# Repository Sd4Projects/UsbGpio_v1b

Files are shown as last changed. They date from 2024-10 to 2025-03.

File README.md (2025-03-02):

# UsbGpio_v1b

Add gpio pins for (Mac, MiniPC, etc) via USB that do not have gpio pins to use.
If you only need a few gpio pins you may want to check out the Adafruit MCP2221 Breakout board Product ID: 4471.

UsbGpio board licensed under CERN OHL v.1.2 (Open Hardware Licence)

See CERN OHL v.1.2 for applicable conditions

http://ohwr.org/cernohl

USB Gpio Expansion board

Testing board design:

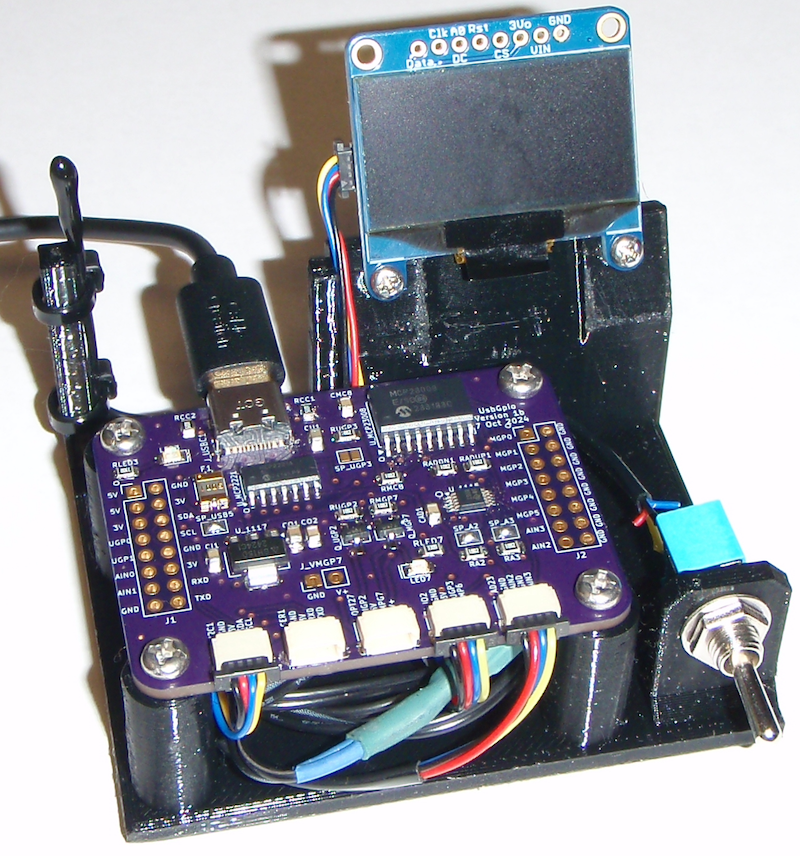
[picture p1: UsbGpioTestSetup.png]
finishedboard


Top view of board:

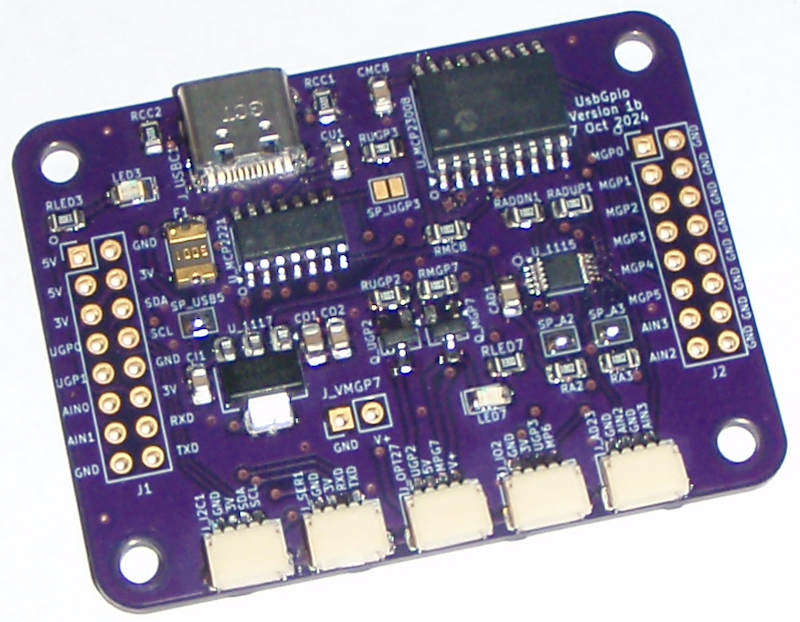
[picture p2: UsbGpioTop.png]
TopView


Bottom view of board:

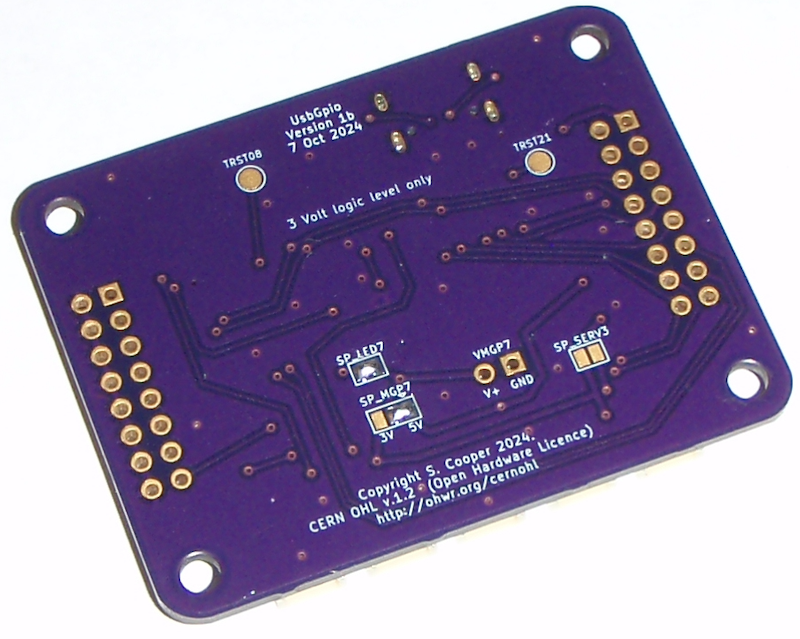
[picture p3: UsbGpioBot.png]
BottomView


Schematic PDF file: UsbGpio_v1b.SCH.pdf

Board PDF file: UsbGpio_v1b.PCB.pdf

BOM PDF file: UsbGpio_v1b.BOM.pdf

Designed with KiCad Version 8.0.4

UsbGpio source files included.

UsbGpio board features:
1. Four 16bit AtoD lines using an ADS1115 chip via I2C interface
2. MCP23008 chip via I2C interface
3. Two GPIO pins driving 2N7002 Mosfets for output.
4. I2C lines to a JST_SH Connector
5. UART (Serial) lines to a JST_SH Connector
6. USB C connector, USB 2.0

All data lines use 4-pin Qwiic/JST_SH connectores.

Bare board can be ordered from: https://oshpark.com/shared_projects/wGhxM2sL

Python 3 test program run on a Mac from Terminal window: macTestMcp2221.py (There are python libraries for other types of systems.)

Parts used for testing:
1. 10K Precision Epoxy Thermistor - 3950 NTC From adafruit Product ID: 372
2. Monochrome 1.3" 128x64 OLED graphic display - STEMMA QT / Qwiic From adafruit Product ID: 938
3. Mini Panel Mount SPDT Toggle Switch From adafruit Product ID: 3221
4. STEMMA QT / Qwiic JST SH 4-Pin Cable - 50mm Long From adafruit Product ID: 4399

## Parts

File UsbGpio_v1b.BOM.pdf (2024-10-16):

### UsbGpio

Reference | Qty | Value | Digi-Key_PN | Manufacturer Part# | Footprint
CAD1,CMC8,CO2 | 3 | 0.1uF | 399-C0805C104K3RAC7800CT-ND | C0805C104K3RAC7800 | Capacitor_SMD:C_0805_2012Metric_Pad1.18x1.45mm_HandSolder
CI1,CU1 | 2 | 1uF | 1276-1029-1-ND | CL21B105KBFNNNE | Capacitor_SMD:C_0805_2012Metric_Pad1.18x1.45mm_HandSolder
CO1 | 1 | 4.7uF | 399-5505-1-ND | C0805C475K3PACTU | Capacitor_SMD:C_0805_2012Metric_Pad1.18x1.45mm_HandSolder
F1 | 1 | 500ma | MF-PSMF050X-2CT-ND | MF-MSMF050-2 | Fuse:Fuse_1812_4532Metric
J1,J2 | 2 | Conn_02x08_Odd_Even | | | Connector_PinHeader_2.54mm:PinHeader_2x08_P2.54mm_Vertical
J_AD23,J_I2C1,J_IO2,J_OPT27,J_SER1 | 5 | Conn_01x04_MountingPin | 455-SM04B-SRSS-TBCT-ND | SM04B-SRSS-TB | Connector_JST:JST_SH_SM04B-SRSS-TB_1x04-1MP_P1.00mm_Horizontal
J_USBC1 | 1 | USB_C_Receptacle_USB2.0 | 2073-USB4105-GF-ACT-ND | USB4105-GF-A | UsbGpio:USB_C_Receptacle_Palconn_UTC16-G_MOD
J_VMGP7 | 1 | Conn_01x02 | | | Connector_PinHeader_2.54mm:PinHeader_1x02_P2.54mm_Vertical
LED3 | 1 | yellow | 160-1416-1-ND | LTST-C170KSKT | LED_SMD:LED_0805_2012Metric_Pad1.15x1.40mm_HandSolder
LED7 | 1 | blue | 160-1645-1-ND | C171TBKT | LED_SMD:LED_0805_2012Metric_Pad1.15x1.40mm_HandSolder
Q_MGP7,Q_UGP2 | 2 | 2N7002K | 2N7002KCT-ND | 2N7002K | Package_TO_SOT_SMD:SOT-23_Handsoldering
RA2,RA3,RADDN1,RADUP1,RMC8,RMGP7,RUGP2,RUGP3 | 8 | 10K | 311-10KLGCT-ND | AC0805FR-0710KL | Resistor_SMD:R_0805_2012Metric_Pad1.20x1.40mm_HandSolder
RCC1,RCC2 | 2 | 5K1 | 311-5.10KCRCT-ND | RC0805FR-075K1L | Resistor_SMD:R_0805_2012Metric
RLED3,RLED7 | 2 | 330 | 311-330CRCT-ND | RC0805FR-07330RL | Resistor_SMD:R_0805_2012Metric
U_1115 | 1 | ADS1115 | 296-24934-1-ND | ADS1115IDGST | UsbGpio:MSOP-10_3x3mm_P0.5mm_MOD
U_1117 | 1 | AZ1117-3.3 | AZ1117CH-3.3TRG1DICT-ND | AZ1117CH-3.3TRG1 | Package_TO_SOT_SMD:SOT-223-3_TabPin2
U_MCP2221 | 1 | MCP2221AxSL | MCP2221A-I/SL-ND | MCP2221A-I/SL | Package_SO:SOIC-14_3.9x8.7mm_P1.27mm
U_MCP23008 | 1 | MCP23008-xSO | MCP23008T-E/SOCT-ND | MCP23008T-E/SO | Package_SO:SOIC-18W_7.5x11.6mm_P1.27mm

1

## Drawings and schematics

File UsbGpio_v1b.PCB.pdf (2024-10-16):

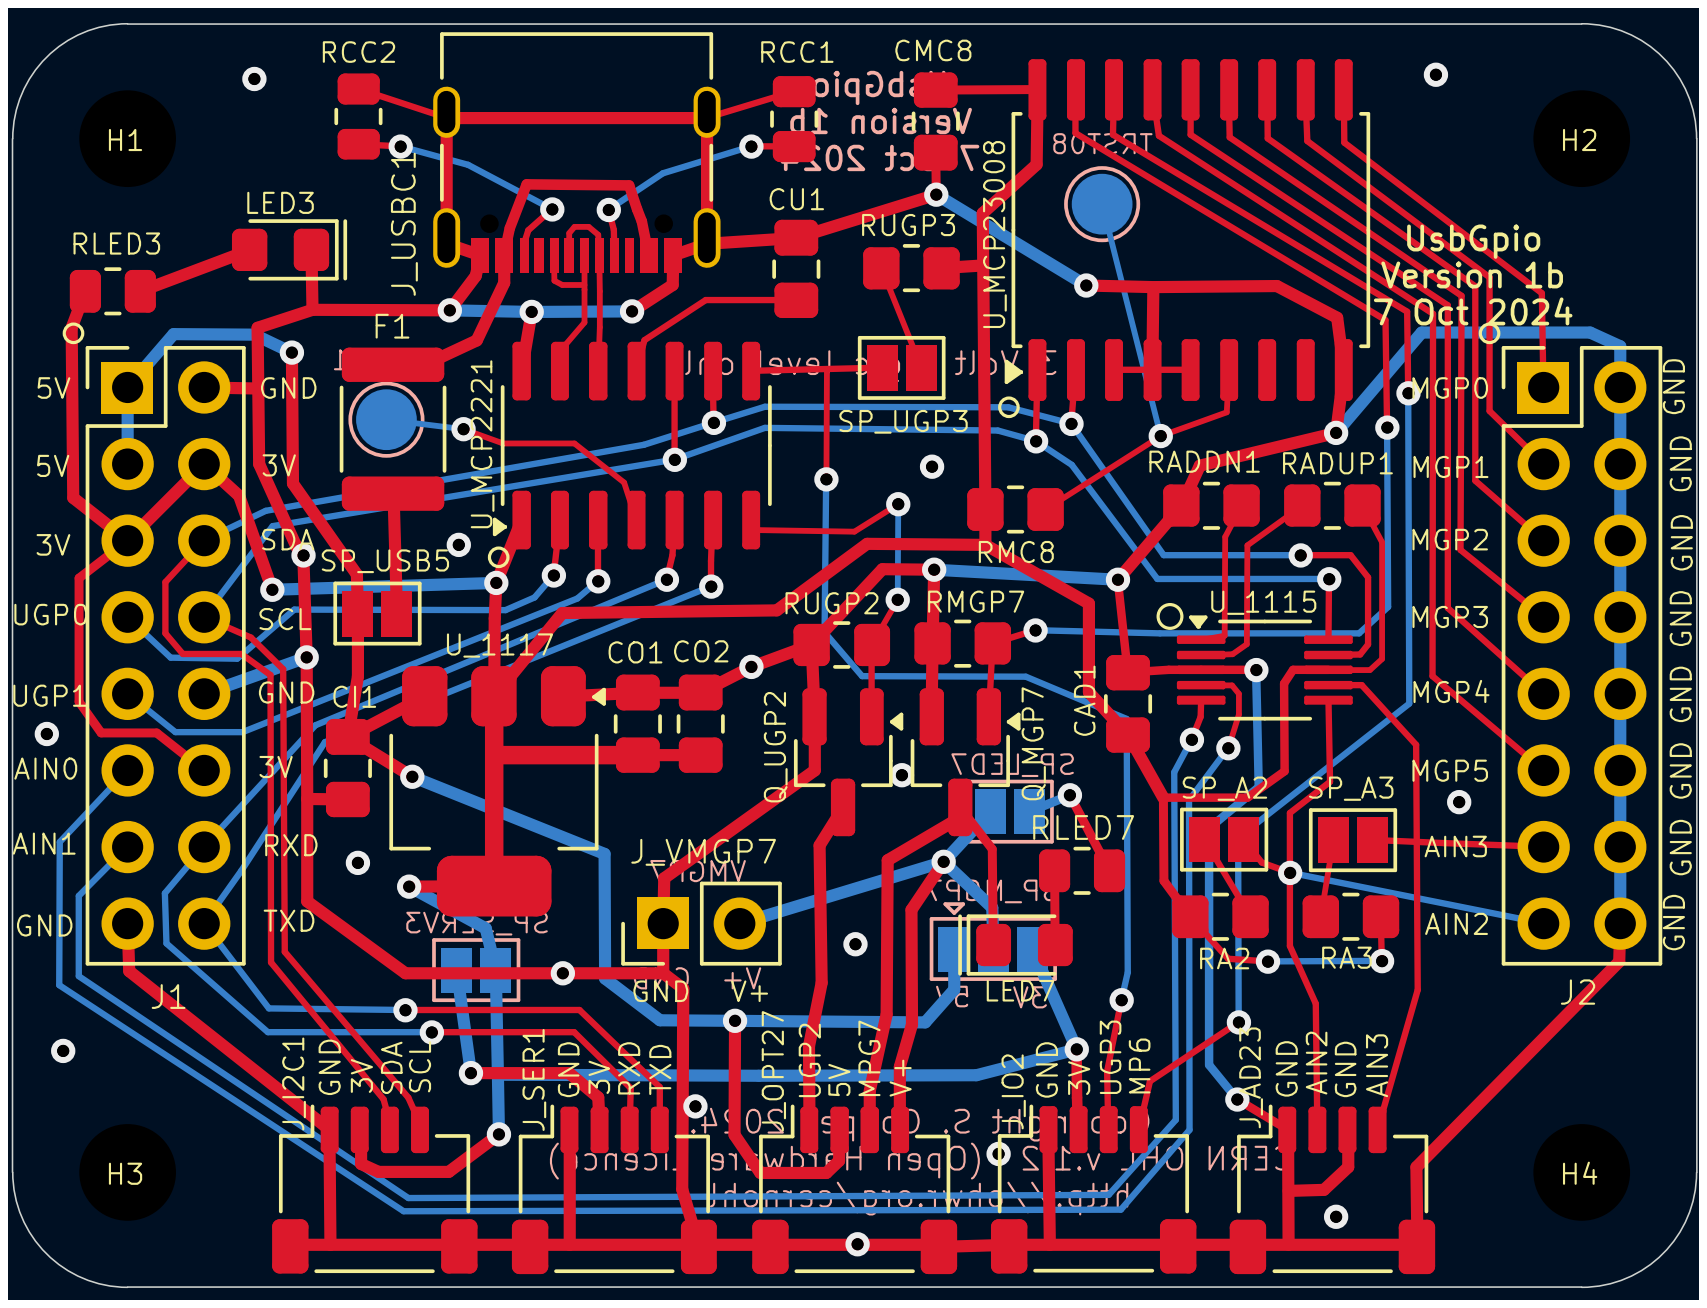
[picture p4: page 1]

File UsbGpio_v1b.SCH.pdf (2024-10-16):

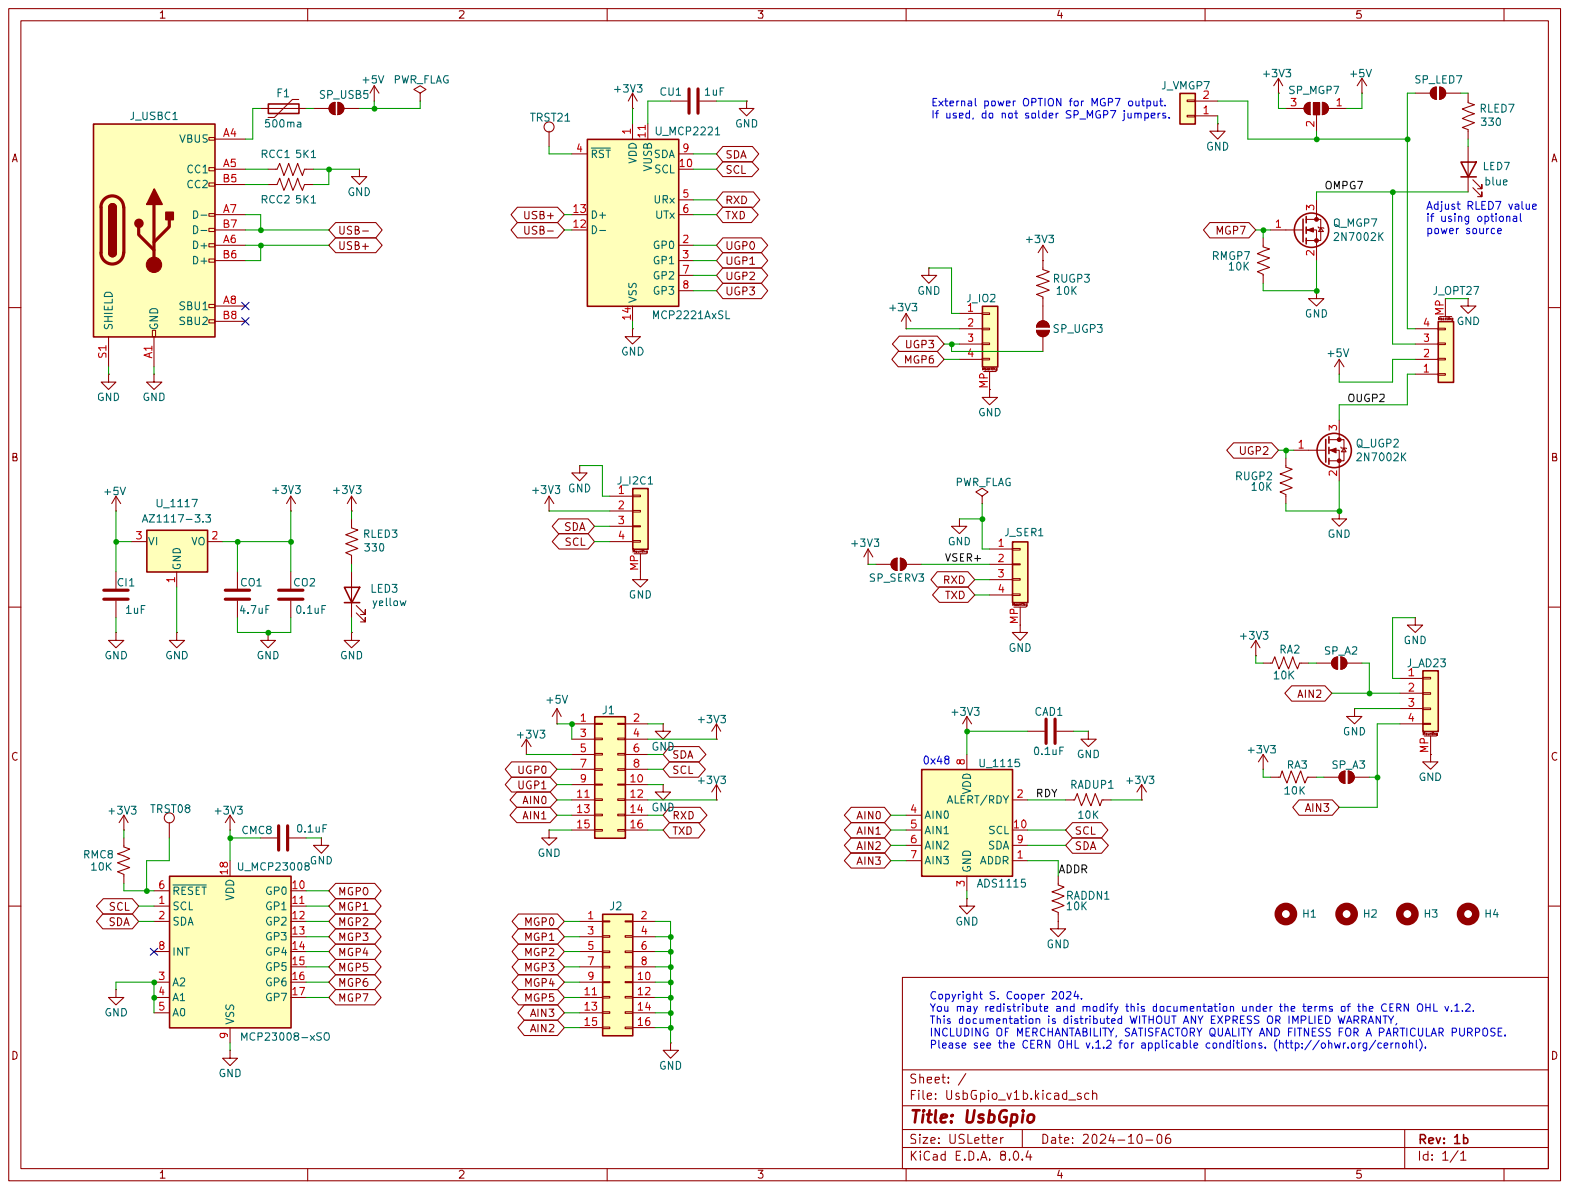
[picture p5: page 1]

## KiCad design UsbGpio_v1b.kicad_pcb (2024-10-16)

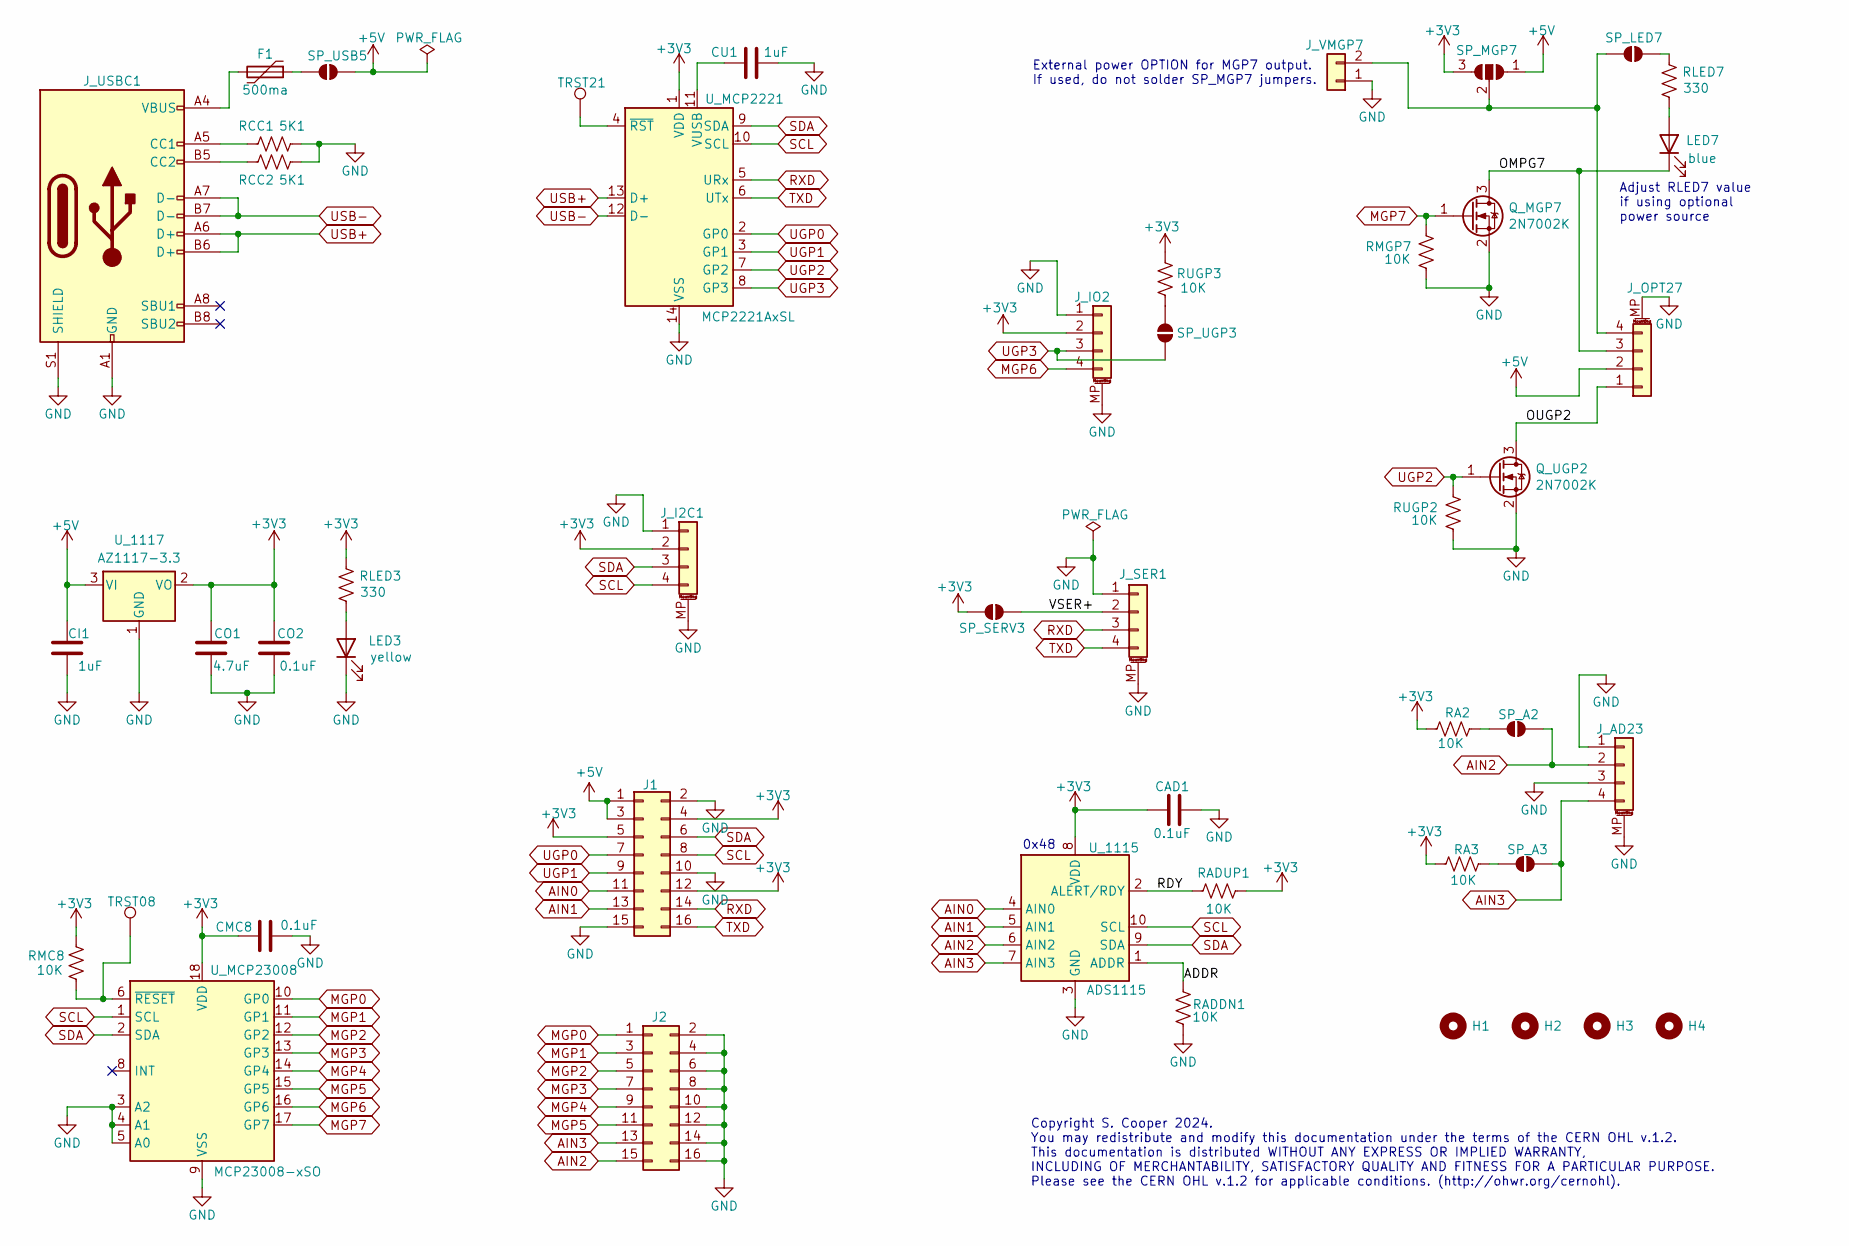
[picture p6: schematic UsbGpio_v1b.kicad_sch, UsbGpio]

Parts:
CAD1: 0.1uF; C_0805_2012Metric_Pad1.18x1.45mm_HandSolder; Manufacturer Part# C0805C104K3RAC7800; Digi-Key_PN 399-C0805C104K3RAC7800CT-ND
CI1: 1uF; C_0805_2012Metric_Pad1.18x1.45mm_HandSolder; Manufacturer Part# CL21B105KBFNNNE; Digi-Key_PN 1276-1029-1-ND
CMC8: 0.1uF; C_0805_2012Metric_Pad1.18x1.45mm_HandSolder; Manufacturer Part# C0805C104K3RAC7800; Digi-Key_PN 399-C0805C104K3RAC7800CT-ND
CO1: 4.7uF; C_0805_2012Metric_Pad1.18x1.45mm_HandSolder; Manufacturer Part# C0805C475K3PACTU; Digi-Key_PN 399-5505-1-ND
CO2: 0.1uF; C_0805_2012Metric_Pad1.18x1.45mm_HandSolder; Manufacturer Part# C0805C104K3RAC7800; Digi-Key_PN 399-C0805C104K3RAC7800CT-ND
CU1: 1uF; C_0805_2012Metric_Pad1.18x1.45mm_HandSolder; Manufacturer Part# CL21B105KBFNNNE; Digi-Key_PN 1276-1029-1-ND
F1: 500ma; Fuse_1812_4532Metric; Manufacturer Part# MF-MSMF050-2; Digi-Key_PN MF-PSMF050X-2CT-ND
H1, H2, H3, H4: MountingHole; MountingHole_3.2mm_M3
J1, J2: Conn_02x08_Odd_Even; PinHeader_2x08_P2.54mm_Vertical
J_AD23: Conn_01x04_MountingPin; JST_SH_SM04B-SRSS-TB_1x04-1MP_P1.00mm_Horizontal; Manufacturer Part# SM04B-SRSS-TB; Digi-Key_PN 455-SM04B-SRSS-TBCT-ND
J_I2C1: Conn_01x04_MountingPin; JST_SH_SM04B-SRSS-TB_1x04-1MP_P1.00mm_Horizontal; Manufacturer Part# SM04B-SRSS-TB; Digi-Key_PN 455-SM04B-SRSS-TBCT-ND
J_IO2: Conn_01x04_MountingPin; JST_SH_SM04B-SRSS-TB_1x04-1MP_P1.00mm_Horizontal; Manufacturer Part# SM04B-SRSS-TB; Digi-Key_PN 455-SM04B-SRSS-TBCT-ND
J_OPT27: Conn_01x04_MountingPin; JST_SH_SM04B-SRSS-TB_1x04-1MP_P1.00mm_Horizontal; Manufacturer Part# SM04B-SRSS-TB; Digi-Key_PN 455-SM04B-SRSS-TBCT-ND
J_SER1: Conn_01x04_MountingPin; JST_SH_SM04B-SRSS-TB_1x04-1MP_P1.00mm_Horizontal; Manufacturer Part# SM04B-SRSS-TB; Digi-Key_PN 455-SM04B-SRSS-TBCT-ND
J_USBC1: USB_C_Receptacle_USB2.0; USB_C_Receptacle_Palconn_UTC16-G_MOD; Manufacturer Part# USB4105-GF-A; Digi-Key_PN 2073-USB4105-GF-ACT-ND
J_VMGP7: Conn_01x02; PinHeader_1x02_P2.54mm_Vertical
LED3: yellow; LED_0805_2012Metric_Pad1.15x1.40mm_HandSolder; Manufacturer Part# LTST-C170KSKT; Digi-Key_PN 160-1416-1-ND
LED7: blue; LED_0805_2012Metric_Pad1.15x1.40mm_HandSolder; Manufacturer Part# C171TBKT; Digi-Key_PN 160-1645-1-ND
Q_MGP7: 2N7002K; SOT-23_Handsoldering; Manufacturer Part# 2N7002K; Digi-Key_PN 2N7002KCT-ND
Q_UGP2: 2N7002K; SOT-23_Handsoldering; Manufacturer Part# 2N7002K; Digi-Key_PN 2N7002KCT-ND
RA2, RA3: 10K; R_0805_2012Metric_Pad1.20x1.40mm_HandSolder; Manufacturer Part# AC0805FR-0710KL; Digi-Key_PN 311-10KLGCT-ND
RADDN1: 10K; R_0805_2012Metric_Pad1.20x1.40mm_HandSolder; Manufacturer Part# AC0805FR-0710KL; Digi-Key_PN 311-10KLGCT-ND
RADUP1: 10K; R_0805_2012Metric_Pad1.20x1.40mm_HandSolder; Manufacturer Part# AC0805FR-0710KL; Digi-Key_PN 311-10KLGCT-ND
RCC1, RCC2: 5K1; R_0805_2012Metric; Manufacturer Part# RC0805FR-075K1L; Digi-Key_PN 311-5.10KCRCT-ND
RLED3, RLED7: 330; R_0805_2012Metric; Manufacturer Part# RC0805FR-07330RL; Digi-Key_PN 311-330CRCT-ND
RMC8: 10K; R_0805_2012Metric_Pad1.20x1.40mm_HandSolder; Manufacturer Part# AC0805FR-0710KL; Digi-Key_PN 311-10KLGCT-ND
RMGP7: 10K; R_0805_2012Metric_Pad1.20x1.40mm_HandSolder; Manufacturer Part# AC0805FR-0710KL; Digi-Key_PN 311-10KLGCT-ND
RUGP2, RUGP3: 10K; R_0805_2012Metric_Pad1.20x1.40mm_HandSolder; Manufacturer Part# AC0805FR-0710KL; Digi-Key_PN 311-10KLGCT-ND
SP_A2, SP_A3: SolderJumper_2_Open; SolderJumper-2_P1.3mm_Open_Pad1.0x1.5mm
SP_LED7: SolderJumper_2_Open; SolderJumper-2_P1.3mm_Open_Pad1.0x1.5mm
SP_MGP7: SolderJumper_3_Open; SolderJumper-3_P1.3mm_Open_Pad1.0x1.5mm
SP_SERV3: SolderJumper_2_Open; SolderJumper-2_P1.3mm_Open_Pad1.0x1.5mm
SP_UGP3: SolderJumper_2_Open; SolderJumper-2_P1.3mm_Open_Pad1.0x1.5mm
SP_USB5: SolderJumper_2_Open; SolderJumper-2_P1.3mm_Open_Pad1.0x1.5mm
TRST08, TRST21: TestPoint; TestPoint_Pad_D2.0mm
U_1115: ADS1115; MSOP-10_3x3mm_P0.5mm_MOD; Manufacturer Part# ADS1115IDGST; Digi-Key_PN 296-24934-1-ND
U_1117: AZ1117-3.3; SOT-223-3_TabPin2; Manufacturer Part# AZ1117CH-3.3TRG1; Digi-Key_PN AZ1117CH-3.3TRG1DICT-ND
U_MCP2221: MCP2221AxSL; SOIC-14_3.9x8.7mm_P1.27mm; Manufacturer Part# MCP2221A-I/SL; Digi-Key_PN MCP2221A-I/SL-ND
U_MCP23008: MCP23008-xSO; SOIC-18W_7.5x11.6mm_P1.27mm; Manufacturer Part# MCP23008T-E/SO; Digi-Key_PN MCP23008T-E/SOCT-ND

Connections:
+3V3: CAD1.2, CMC8.2, CO1.1, CO2.1, J1.4, J1.5, J1.12, J_I2C1.2, J_IO2.2, RA2.2, RA3.2, RADUP1.2, RLED3.2, RMC8.2, RUGP3.1, SP_MGP7.3 (B), SP_SERV3.1 (A), U_1115.8 (VDD), U_1117.2 (VO), U_MCP2221.1 (VDD), U_MCP23008.18 (VDD)
+5V: CI1.1, J1.1, J1.3, J_OPT27.2, SP_MGP7.1 (A), SP_USB5.2 (B), U_1117.3 (VI)
/ADDR: RADDN1.2, U_1115.1 (ADDR)
/OMPG7: J_OPT27.3, LED7.1 (K), Q_MGP7.3 (D)
/OUGP2: J_OPT27.1, Q_UGP2.3 (D)
/RDY: RADUP1.1, U_1115.2 (ALERT/RDY)
/VSER+: J_SER1.2, SP_SERV3.2 (B)
AIN0: J1.11, U_1115.4 (AIN0)
AIN1: J1.13, U_1115.5 (AIN1)
AIN2: J2.15, J_AD23.2, SP_A2.1 (A), U_1115.6 (AIN2)
AIN3: J2.13, J_AD23.4, SP_A3.1 (A), U_1115.7 (AIN3)
GND: CAD1.1, CI1.2, CMC8.1, CO1.2, CO2.2, CU1.2, J1.2, J1.10, J1.15, J2.2, J2.4, J2.6, J2.8, J2.10, J2.12, J2.14, J2.16, J_AD23.1, J_AD23.3, J_AD23.MP (MountPin), J_I2C1.1, J_I2C1.MP (MountPin), J_IO2.1, J_IO2.MP (MountPin), J_OPT27.MP (MountPin), J_SER1.1, J_SER1.MP (MountPin), J_USBC1.A1 (GND), J_USBC1.A12 (GND), J_USBC1.B1 (GND), J_USBC1.B12 (GND), J_USBC1.S1 (SHIELD), J_VMGP7.1, LED3.1 (K), Q_MGP7.2 (S), Q_UGP2.2 (S), RADDN1.1, RCC1.2, RCC2.2, RMGP7.2, RUGP2.2, U_1115.3 (GND), U_1117.1 (GND), U_MCP2221.14 (VSS), U_MCP23008.3 (A2), U_MCP23008.4 (A1), U_MCP23008.5 (A0), U_MCP23008.9 (VSS)
MGP0: J2.1, U_MCP23008.10 (GP0)
MGP1: J2.3, U_MCP23008.11 (GP1)
MGP2: J2.5, U_MCP23008.12 (GP2)
MGP3: J2.7, U_MCP23008.13 (GP3)
MGP4: J2.9, U_MCP23008.14 (GP4)
MGP5: J2.11, U_MCP23008.15 (GP5)
MGP6: J_IO2.4, U_MCP23008.16 (GP6)
MGP7: Q_MGP7.1 (G), RMGP7.1, U_MCP23008.17 (GP7)
unnamed: F1.2, J_USBC1.A4 (VBUS), J_USBC1.A9 (VBUS), J_USBC1.B4 (VBUS), J_USBC1.B9 (VBUS)
unnamed: J_OPT27.4, J_VMGP7.2, SP_LED7.1 (A), SP_MGP7.2 (C)
unnamed: J_USBC1.A5 (CC1), RCC1.1
unnamed: J_USBC1.B5 (CC2), RCC2.1
unnamed: LED3.2 (A), RLED3.1
unnamed: LED7.2 (A), RLED7.1
unnamed: RA2.1, SP_A2.2 (B)
unnamed: RA3.1, SP_A3.2 (B)
unnamed: RLED7.2, SP_LED7.2 (B)
unnamed: RUGP3.2, SP_UGP3.1 (A)
unnamed: F1.1, SP_USB5.1 (A)
unnamed: CU1.1, U_MCP2221.11 (VUSB)
unnamed: TRST21.1, U_MCP2221.4 (~RST)
unnamed: RMC8.1, TRST08.1, U_MCP23008.6 (~RESET)
RXD: J1.14, J_SER1.3, U_MCP2221.5 (URx)
SCL: J1.8, J_I2C1.4, U_1115.10 (SCL), U_MCP2221.10 (SCL), U_MCP23008.1 (SCL)
SDA: J1.6, J_I2C1.3, U_1115.9 (SDA), U_MCP2221.9 (SDA), U_MCP23008.2 (SDA)
TXD: J1.16, J_SER1.4, U_MCP2221.6 (UTx)
UGP0: J1.7, U_MCP2221.2 (GP0)
UGP1: J1.9, U_MCP2221.3 (GP1)
UGP2: Q_UGP2.1 (G), RUGP2.1, U_MCP2221.7 (GP2)
UGP3: J_IO2.3, SP_UGP3.2 (B), U_MCP2221.8 (GP3)
USB+: J_USBC1.A6 (D+), J_USBC1.B6 (D+), U_MCP2221.13 (D+)
USB-: J_USBC1.A7 (D-), J_USBC1.B7 (D-), U_MCP2221.12 (D-)

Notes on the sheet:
External power OPTION for MGP7 output. If used, do not solder SP_MGP7 jumpers.
0x48
Adjust RLED7 value if using optional power source
Copyright S. Cooper 2024. You may redistribute and modify this documentation under the terms of the CERN OHL v.1.2. This documentation is distributed WITHOUT ANY EXPRESS OR IMPLIED WARRANTY, INCLUDING OF MERCHANTABILITY, SATISFACTORY QUALITY AND FITNESS FOR A PARTICULAR PURPOSE. Please see the CERN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

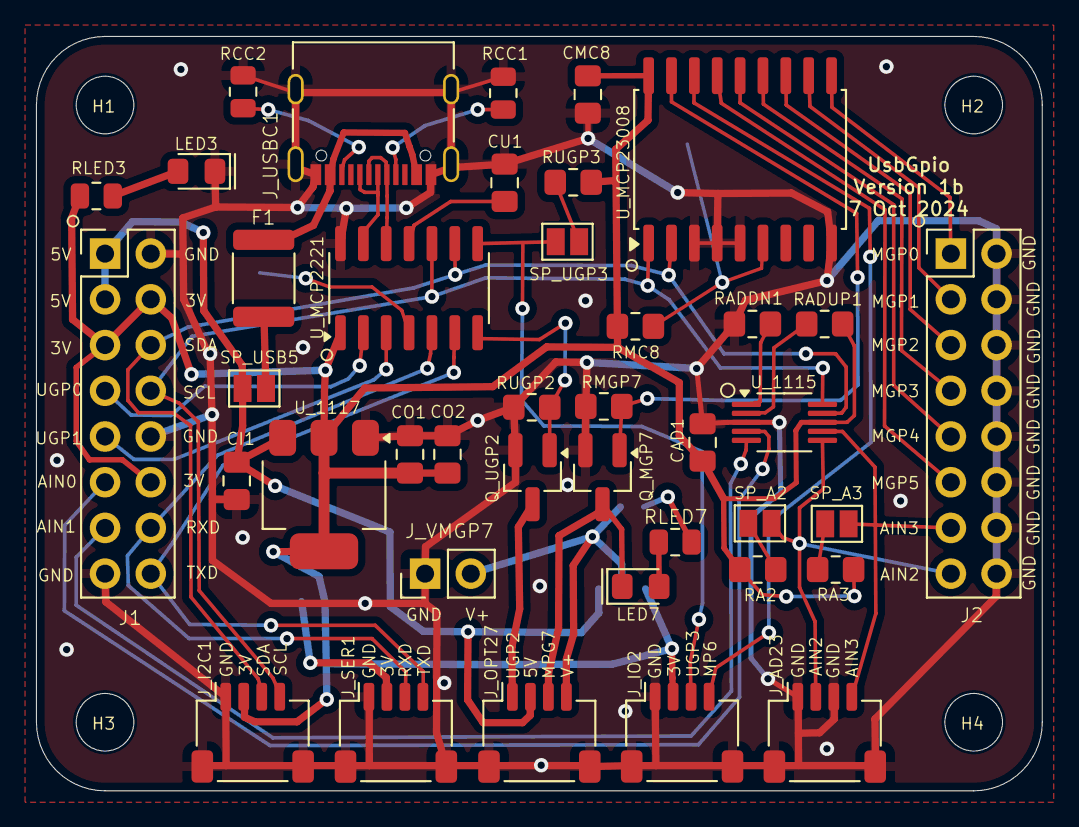
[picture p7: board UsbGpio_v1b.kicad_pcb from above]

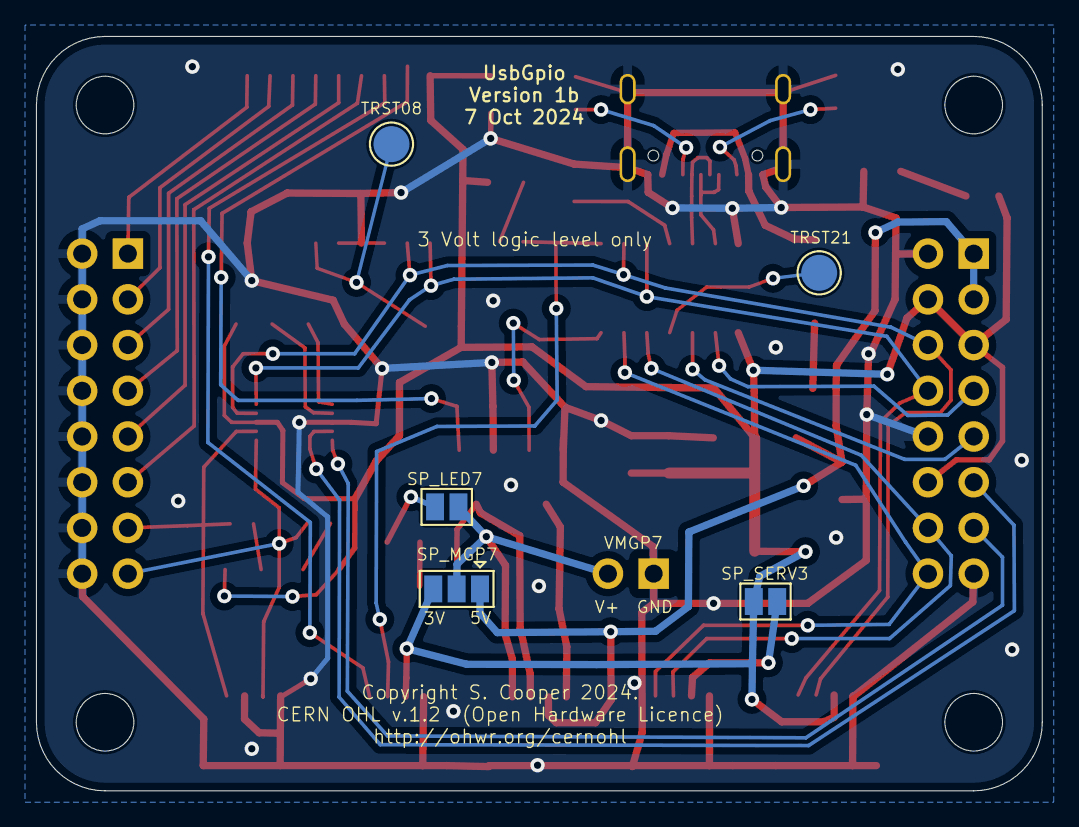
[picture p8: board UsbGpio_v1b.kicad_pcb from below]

Board: 2 copper layers, 55.9 x 41.9 mm, 49 parts (5 on the bottom side), 44 nets.

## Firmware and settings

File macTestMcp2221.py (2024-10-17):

#!/Library/Frameworks/Python.framework/Versions/3.12/bin/python3

# This program released under OHL Version 1.2

# pip3 install adafruit-blinka
# pip3 install adafruit-circuitpython-mcp230xx
# pip3 install adafruit-circuitpython-ads1x15
# pip3 install adafruit-circuitpython-ssd1306
# Install missing font, font5x8.bin from github
# https://github.com/adafruit/Adafruit_CircuitPython_framebuf/blob/master/examples/font5x8.bin
# font5x8.bin must same be in the same directory as program to use adafruit_ssd1306

import os
os.environ['BLINKA_MCP2221'] = '1'
os.environ['BLINKA_MCP2221_RESET_DELAY'] = '0.5'
import sys
import time
import math
import board
import digitalio
import adafruit_ssd1306
import adafruit_ads1x15.ads1115 as ADS
from adafruit_ads1x15.analog_in import AnalogIn
from adafruit_mcp230xx.mcp23008 import MCP23008

button = digitalio.DigitalInOut(board.G0)   # not used
button.direction = digitalio.Direction.INPUT

i2c = board.I2C()

# NTC convert parts
R1 = 10000
Vcc = 3.31
Bc = 3950
Tnom = 25
Rntc = 10000

ads = ADS.ADS1115(i2c)                       # 0x48
time.sleep(0.1)                              # wait for setup to finish
adsChan2 = AnalogIn(ads, ADS.P2)             # NTC 10K Therm
mcp = MCP23008(i2c)                          # 0x20

oled = adafruit_ssd1306.SSD1306_I2C(128, 64, i2c, addr=0x3d)
oled.fill(0)
oled.show()

while True:
    Vr2 = adsChan2.voltage
    R2 = Vr2*R1/(Vcc-Vr2)
    steinhart = R2 / Rntc
    steinhart = math.log(steinhart)
    steinhart /= Bc
    steinhart += 1 / (Tnom + 273.15)
    steinhart = 1 / steinhart
    steinhart -= 273.15
    print("C Temp Is: {0:.3f}".format(steinhart))
    gCTempIs = steinhart

    pin6 = mcp.get_pin(6)                        # Switch Test
    pin6.direction = digitalio.Direction.INPUT
    pin6.pull = digitalio.Pull.UP
    switchIs = pin6.value
    pin7 = mcp.get_pin(7)                        # LED Test
    pin7.direction = digitalio.Direction.OUTPUT
    pin7.value = True                            # Turn on LED

    oled.fill(0)
    showText1 = "Ctemp {0:.3f}".format(gCTempIs)
    oled.text(showText1, 30, 10, 1)              # H , V , 1=ON
    if switchIs is True:                         # 1 = Off, 0 = On , pin has pullup
        showText2 = "Switch Off"
    else:
        showText2 = "Switch On "
    oled.text(showText2, 35, 30, 1)              # H , V , 1=ON
    oled.show()

    time.sleep(0.5)
    if switchIs is False:
        pin7.value = False                       # Turn LED off
        oled.text("Done", 50, 50, 1)
        oled.show()
        print("Done")
        sys.exit(0)
